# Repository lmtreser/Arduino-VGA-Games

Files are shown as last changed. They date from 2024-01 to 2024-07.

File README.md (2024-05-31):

# Arduino VGA Games

Implementación de videojuegos mediante la biblioteca [VGAX de Sandro Maffiodo](https://github.com/smaffer/vgax), un trabajo de [@Rob+Cai](https://www.instructables.com/member/Rob+Cai/). En el foro de Arduino hay un hilo ["Arduino color game (Bomber) using VGA library"](https://forum.arduino.cc/t/arduino-color-game-bomber-using-vga-library/316899) con más información y distintas versiones de juegos.

Uno de los juegos incluidos es [Pong! de Atari](https://es.wikipedia.org/wiki/Pong), el primer videojuego digital. A diferencia de otros, Pong utilizó un circuito totalmente digital para producir los gráficos, el sonido y el control del juego. No hay software ni CPU, sólo una colección de 66 circuitos integrados discretos que realizan una única función, interconectados para crear el juego que conocemos. En **/docs/PongSchematics.pdf** está el diagrama esquemático de la versión arcade original.

## Algunas fotos del primer prototipo

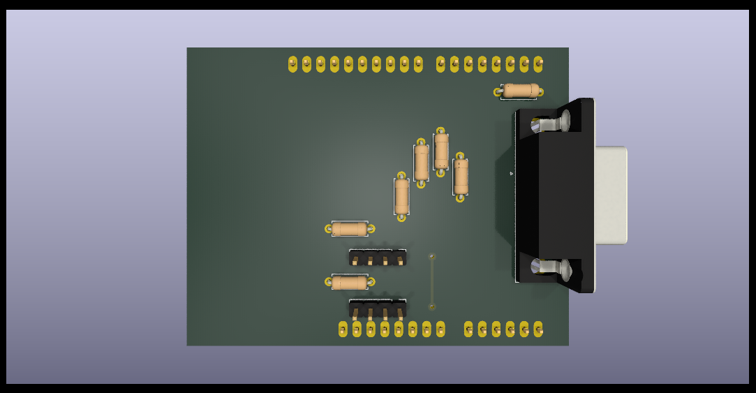
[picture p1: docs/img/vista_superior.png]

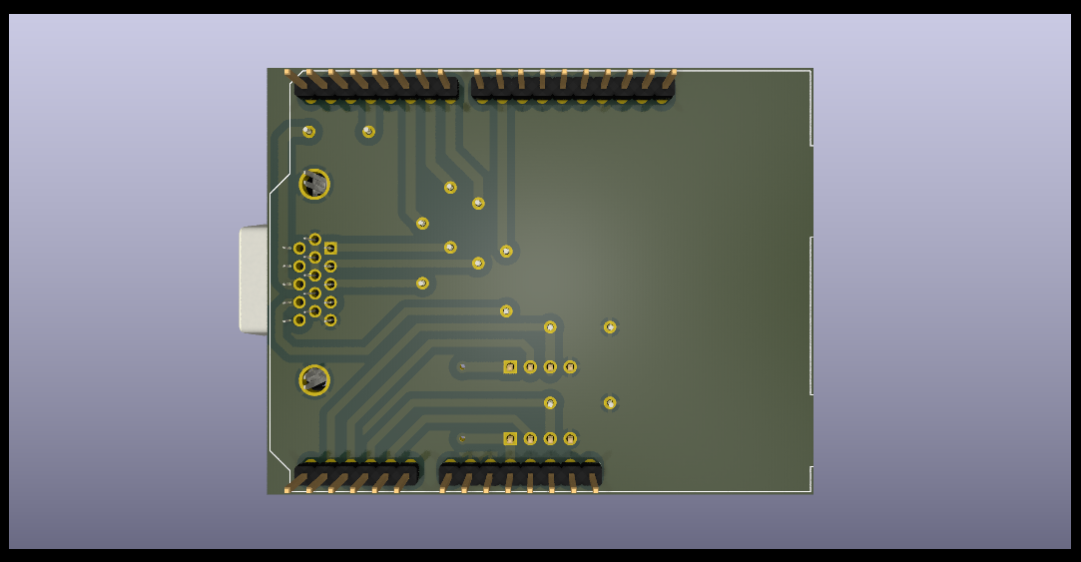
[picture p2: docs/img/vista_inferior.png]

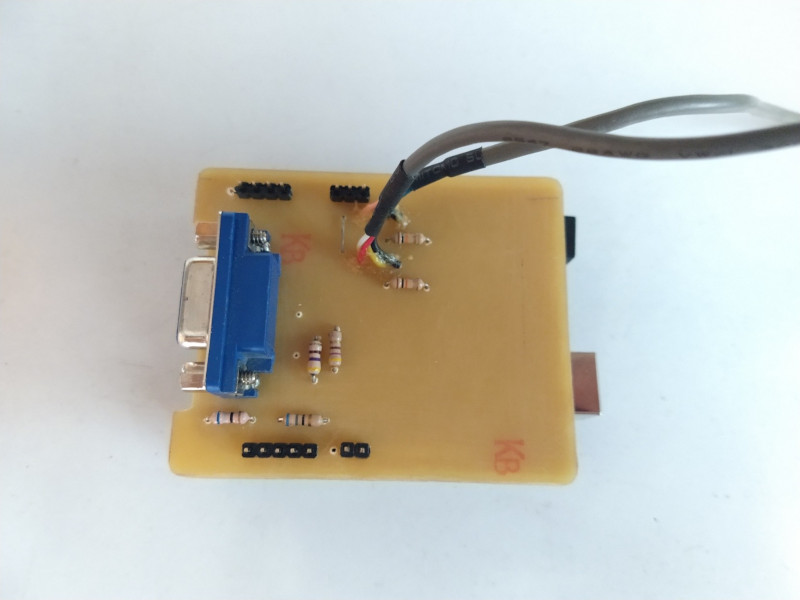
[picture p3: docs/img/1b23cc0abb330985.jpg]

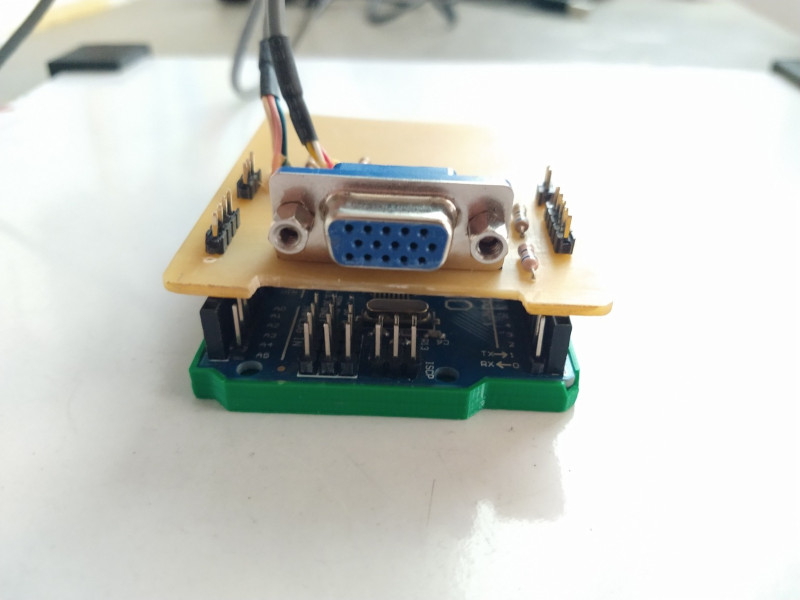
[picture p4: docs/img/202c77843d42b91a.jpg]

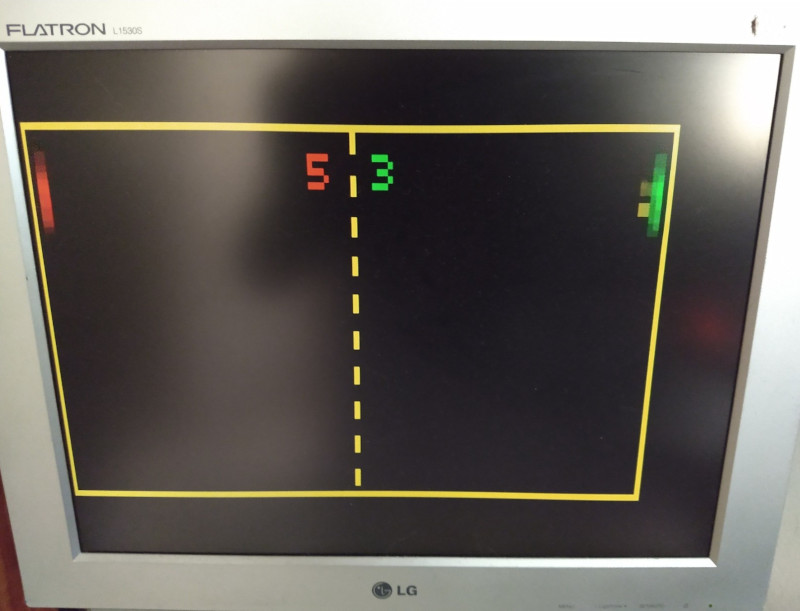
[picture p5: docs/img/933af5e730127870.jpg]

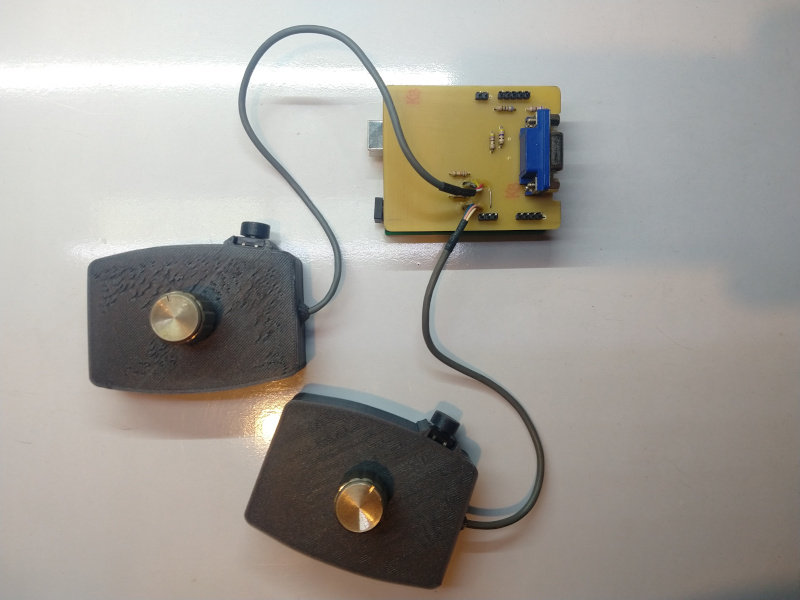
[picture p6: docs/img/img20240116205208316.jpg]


## Recursos

- Instructable ["VGA Games 4-in-1"](https://www.instructables.com/Arduino-VGA-Games-4-in-1/)
- Instructable ["Pong With Arduino Uno"](https://www.instructables.com/VGA-Pong-with-Arduino-Uno/)
- Biblioteca ["VGAX Library for Arduino UNO and MEGA"](https://github.com/smaffer/vgax)
- Otra biblioteca para explorar: ["APL"](https://github.com/akund/APL)
- Gabinete 3D ["USB paddle game controller"](https://www.thingiverse.com/thing:4223937)
- [The original Pong video game had no code](https://www.reddit.com/r/EngineeringPorn/comments/ul49zt/the_original_pong_video_game_had_no_code_and_was/)
- [Fabricating Hardware From The Original Arcade Pong Schematics](https://hackaday.com/2012/12/22/fabricating-hardware-from-the-original-arcade-pong-schematics/)

## Licencia

Tanto la **biblioteca VGAX** como el **firmware original de Rob+Cai** están protegidas por sus respectivas licencias, por favor consulte los sitios donde se alojan para mayor información. El resto del trabajo está protegido por la **Licencia MIT**. Puedes acceder a la versión original de la licencia (en inglés) a través del archivo [LICENSE](./LICENSE) o en línea en [The MIT License (MIT)](https://mit-license.org/). También proporcionamos una traducción no oficial desde [Wikipedia](https://es.m.wikipedia.org/wiki/Licencia_MIT#La_licencia):

Copyright (c) 2024 Lucas Martín Treser

Por la presente se concede permiso, libre de cargos, a cualquier persona que obtenga una copia de este software y de los archivos de documentación asociados (el "Software"), a utilizar el Software sin restricción, incluyendo sin limitación los derechos a usar, copiar, modificar, fusionar, publicar, distribuir, sublicenciar, y/o vender copias del Software, y a permitir a las personas a las que se les proporcione el Software a hacer lo mismo, sujeto a las siguientes condiciones:

El aviso de copyright anterior y este aviso de permiso se incluirán en todas las copias o partes sustanciales del Software.

EL SOFTWARE SE PROPORCIONA "COMO ESTÁ", SIN GARANTÍA DE NINGÚN TIPO, EXPRESA O IMPLÍCITA, INCLUYENDO PERO NO LIMITADO A GARANTÍAS DE COMERCIALIZACIÓN, IDONEIDAD PARA UN PROPÓSITO PARTICULAR E INCUMPLIMIENTO. EN NINGÚN CASO LOS AUTORES O PROPIETARIOS DE LOS DERECHOS DE AUTOR SERÁN RESPONSABLES DE NINGUNA RECLAMACIÓN, DAÑOS U OTRAS RESPONSABILIDADES, YA SEA EN UNA ACCIÓN DE CONTRATO, AGRAVIO O CUALQUIER OTRO MOTIVO, DERIVADAS DE, FUERA DE O EN CONEXIÓN CON EL SOFTWARE O SU USO U OTRO TIPO DE ACCIONES EN EL SOFTWARE.

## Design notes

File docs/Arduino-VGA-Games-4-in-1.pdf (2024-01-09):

http://www.instructables.com/id/Arduino-VGA-Games-4-in-1/technology (http://www.instructables.com/tag/type-id/category-technology/) workshop (http://www.instructables.com/tag/type-id/category-workshop/) craft (http://www.instructables.com/tag/type-id/category-craft/) home (http://www.instructables.com/tag/type-id/category-home/) food (http://www.instructables.com/tag/type-id/category-food/) play (http://www.instructables.com/tag/type-id/category-play/) outside (http://www.instructables.com/tag/type-id/category-outside/) costumes (http://www.instructables.com/tag/type-id/category-costumes/)

# Arduino VGA games 4-in-1

by Rob Cai on December 29, 2016

Table of Contents

## Intro: Arduino VGA games 4-in-1

After the publication of the Arduino VGAx library (https://github.com/smaffer/vgax) on GitHub done by Sandro Maffiodo aka Smaffer, I have reproduced and published on Instructable some of the most famous classical games. Recently I decided to put four of them together, in particular: Pong, Breakout, Bomber and a drawing toy inspired to Etch-a-Sketch.

The hardware is simply the same of my first Instructables: VGA Pong with Arduino Uno. (http://www.instructables.com/id/VGA-Pong-with-Arduino-Uno/)

The only needed components are two potentiometers, two buttons, few resistors and a DSUB15 (VGA) connector. As usual, no supporting IC or special shields!

You can see the 4-in-1 games in action in this (https://www.youtube.com/watch?v=HupxNI5VUGE) video.

The VGAx library allows to use four color with a resolution of 120 x 60 pixels, not many but enough for this retro-game “console”. The graphic is raw but, thanks to the use of the potentiometers, the games run smoothly. Simple sound effects are available too.

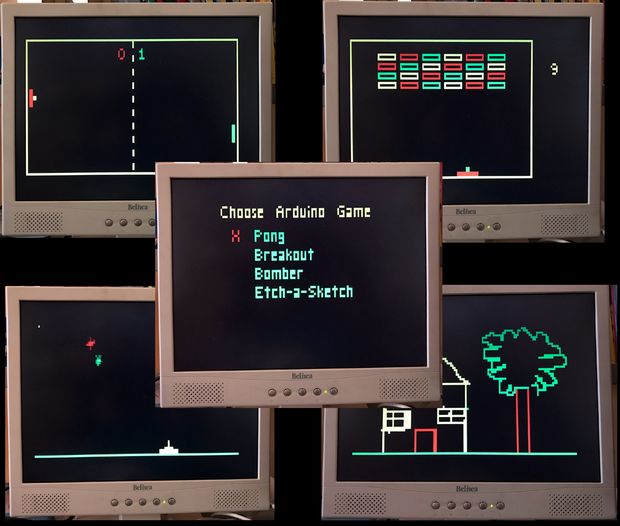
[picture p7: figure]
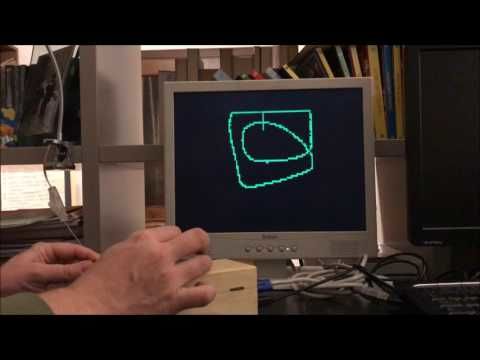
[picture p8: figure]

## Step 1: How to build your own "4-in-1 games" with Arduino

First download " ArduinoVGAgames" code at the bottom of this page and copy it on your PC in a directory with the same name. Then download the Smaffer’s VGAx libraries from this link (https://github.com/smaffer/vgax) on GitHub. The easiest way is to copy them in the Arduino software subfolder named "libraries", to be immediately recognized.

Uploaded then the code in your Arduino (I tested Uno and Nano). A worning for low available memory is normal. If you do not have other errors everything is ok and you can immediately start to build your own console.

For this you need:
an Arduino Uno Rev. 3 or an Arduino Nano 3.x
a DSUB15 Connector, i.e. a VGA female connector or a VGA cable to be cut four resistors: 2 x 68 Ohm and 2 x 470 Ohm
two 10 kOhm linear potentiometers (similar values are fine too)
two buttons other two resistors (from 1 to 2 kOhm are fine)
some piece of cable + breadboard or a strip board
facultative: a piezo speaker

The schematic is reported at the beginning of this Instructable, together with an overview of the finished “console”. The speaker must be connected to analog pin A0.

I placed the Arduino board with the VGA connector in a wood box, which holds also the second player potentiometer and button, while the main player potentiometer and button are in a separate and smaller box.

If you decide to reproduce this toy, I appreciate if you write a comment or send a picture in the comment section below.

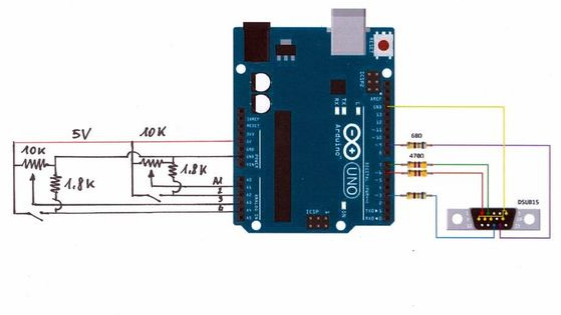
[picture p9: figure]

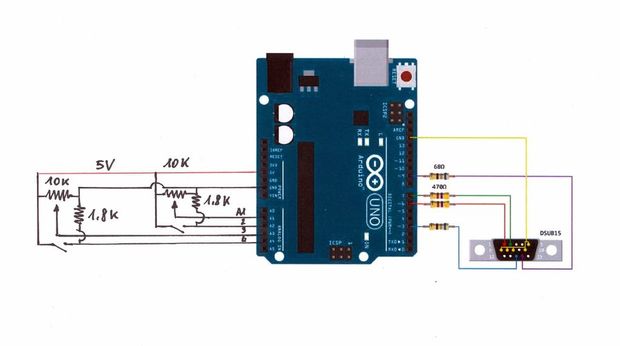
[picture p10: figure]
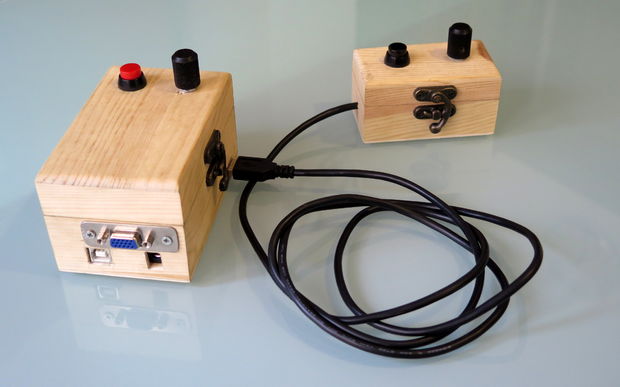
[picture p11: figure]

File Downloads

ArduinoVGAgame.ino (http://www.instructables.comhttps://cdn.instructables.com/ORIG/FQX/OHOC/IX6FVPA1/FQXOHOCIX6FVPA1.ino) (37 KB)

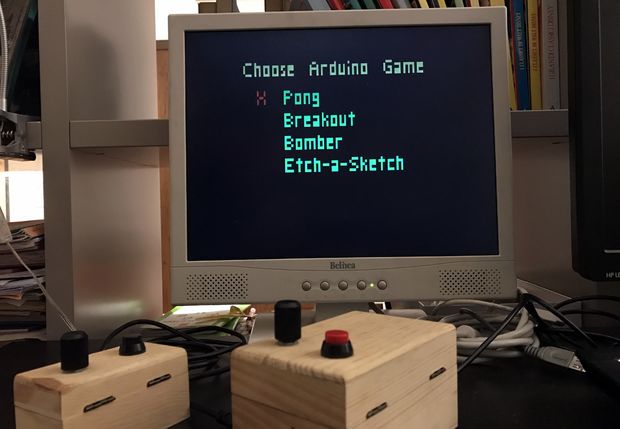
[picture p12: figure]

[NOTE: When saving, if you see .tmp as the file ext, rename it to 'ArduinoVGAgame.ino'] (http://www.instructables.comhttps://cdn.instructables.com/ORIG/FQX/OHOC/IX6FVPA1/FQXOHOCIX6FVPA1.ino)

## Step 2: Some final comment

Joining four games in one was challenging, due to the Arduino lack of SRAM, the real bottle-neck of the VGA performances.

The AVR microcontroller has only 2048 bytes available to store and manipulate the variables. On the other hand the VGAx library stores the screen variables in a 120x60 pixels framebuffer where each pixel needs 2 bits (4 colors), for a total of 1800 bytes.

Only 248 bytes are then available for the sketch variables but, in my experience, one should leave at least 100 bytes free to avoid instabilities.

The VGA standard has been officially put in retirement in 2015, for being substituted with HDMI, and nowadays is almost impossible to find a new monitor or TV that implements it.

The question is then: does it make sense to produce an Arduino game for this standard? Well, I believe the answer is yes! For this reason, nowadays, almost everybody has an old and unused VGA monitor, eventually 4:3, still working fine, since it has been replaced with an HD one. If you, as I do, feel sorry to throw in the waste a working yet obsolete device, you can convert it in an old style retro-gaming station by means of a bare Arduino and few other components.

## Related Instructables

VGA Etch-a-Sketch with
Arduino Uno (http://www.instructables.com/id/VGA-Etch-a-Sketch-With-Arduino-Uno/) by
Rob Cai

VGA Pong with
Arduino Uno (http://www.instructables.com/id/VGA-Pong-with-Arduino-Uno/?utm_source=pdf&utm_campaign=related) by
Rob Cai

VGA Bomber
With Arduino
Uno (http://www.instructables.com/id/VGA-Bomber-With-Arduino-Uno/?utm_source=pdf&utm_campaign=related) by Rob Cai

VGA Snake with
Arduino Uno (http://www.instructables.com/id/VGA-Snake-with-Arduino-Uno/?utm_source=pdf&utm_campaign=related) by
Rob Cai

VGA Breakout
with Arduino
Uno (http://www.instructables.com/id/VGA-Breakout-With-Arduino-Uno/?utm_source=pdf&utm_campaign=related) by Rob Cai

VGA Tetris with
Arduino Uno (http://www.instructables.com/id/VGA-Tetris-With-Arduino-Uno/?utm_source=pdf&utm_campaign=related) by
Rob Cai

Advertisements

## Comments

1 comments | Add Comment (http://www.instructables.com/id/Arduino-VGA-Games-4-in-1/)
PiotrS (http://www.instructables.com/member/PiotrS/?utm_source=pdf&utm_campaign=comments) says: | Dec 29, 2016. 12:45 PM REPLY (http://www.instructables.com/id/Arduino-VGA-Games-4-in-1/)
This is amazing i can show my daughter how it was done in my ages :)

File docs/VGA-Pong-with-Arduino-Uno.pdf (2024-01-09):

http://www.instructables.com/id/VGA-Pong-with-Arduino-Uno/technology (http://www.instructables.com/tag/type-id/category-technology/) workshop (http://www.instructables.com/tag/type-id/category-workshop/) craft (http://www.instructables.com/tag/type-id/category-craft/) home (http://www.instructables.com/tag/type-id/category-home/) food (http://www.instructables.com/tag/type-id/category-food/) play (http://www.instructables.com/tag/type-id/category-play/) outside (http://www.instructables.com/tag/type-id/category-outside/) costumes (http://www.instructables.com/tag/type-id/category-costumes/)

# VGA Pong with Arduino Uno

by Rob Cai on September 17, 2015

Table of Contents

## Intro: VGA Pong with Arduino Uno

I have repruduced a color version of the classic Pong running for a VGA monitor, using a bare Arduino Uno.

It is for two players and it has sound too. It has four colors and a resolution of 120 x 60 pixels.

My goal was to avoid any special shield or support IC!

I just used few resistors, a DSUB15 connector, a pair of potenziometers and buttons. The Arduino board and the others components are placed in two wood boxes. The second player paddle is connected to the main block by means of a recycled USB cable. Pictures of the whole "console" and a simple schematic are shown at the beginning of this video:

In the past I have reproduced the B&W version for TV, using the TVout libraries...

...but now, insted of the TVout library, the color Pong is done using the VGAx library recently written by Smaffer.

You can read further the details in this Arduino forum (http://forum.arduino.cc/index.php?topic=328631.new#new)
Instructions to built your own Color Pong with Arduino

In brief, here (http://forum.arduino.cc/index.php?action=dlattach;topic=328631.0;attach=135889) you can download the latest code version, then you need the VGAx libraries from Smaffer on github published here. (https://github.com/smaffer/vgax)

Once you have the code uploaded an an Arduino Uno (I have Rev. 3) without errors, you can start to build your own console.

You need:
1. an Arduino Uno Rev. 3
2. DSUB15 Connector, i.e. a VGA female connector or a VGA cable to be cut.
3. four resistors: 2 x 68 Ohm and 2 x 470 Ohm
4. two 10 kOhm potentiometers
5. two buttons
6. other two resistors (from 1 to 2 kOhm are fine)
7. some piece of cable
8. facoltative: an USB female plug and an USB cable for the second player, or any other connector/cable with four wires

The schematic is reported at the beginning of this Instructable, together with an overview of the finished consolle and how the game looks on my TV.

I placed the Arduino board with the VGA connector in a wood box, which holds also the first player potentiometer and button. I used a second smaller wood box for the second player and I decided to connect it to the main one by means of an USB female plug and an USB cable. You can use any other connector/cable wich contains at least four separated wires.

Enjoy!

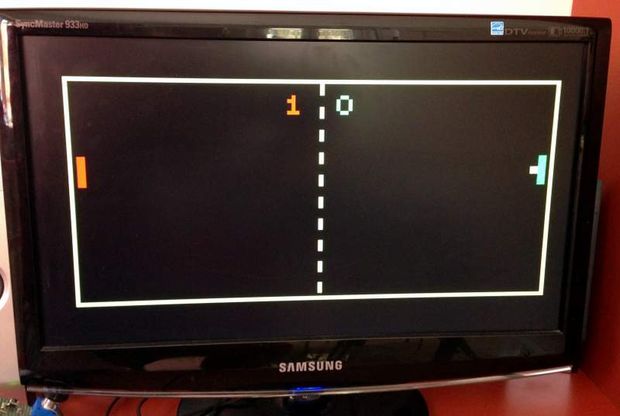
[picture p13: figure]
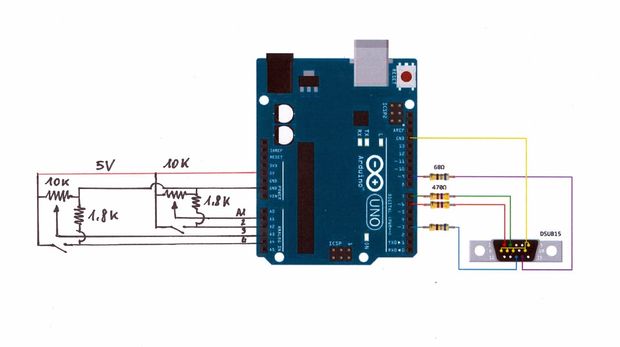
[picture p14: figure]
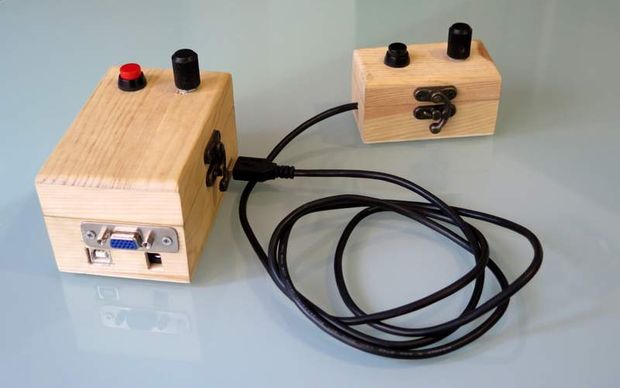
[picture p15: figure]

## Related Instructables

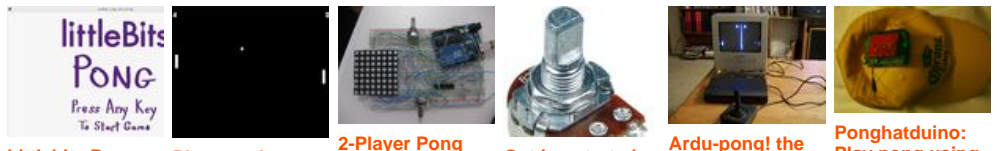
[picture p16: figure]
Ponghatduino:

Littlebits Pong (http://www.instructables.com/id/Littlebits-Pong/?utm_source=pdf&utm_campaign=related)
by Louisville
Public Library

Photo resistor
controlled
arduino pong
with processing (http://www.instructables.com/id/Photo-resistor-controlled-arduino-pong-with-proces/)
by GIV-ENG-2014 (http://www.instructables.com/member/GIV-ENG-2014/?utm_source=pdf&utm_campaign=related)

2-Player Pong
Game Using
Arduino Uno
and 8x8 Led
Matrix (http://www.instructables.com/id/2-Player-Pong-Game-Using-Arduino-Uno-and-8x8-Led-M/) (video) (http://www.instructables.com/id/2-Player-Pong-Game-Using-Arduino-Uno-and-8x8-Led-M/) by
onuravun (http://www.instructables.com/member/onuravun/?utm_source=pdf&utm_campaign=related)

Getting started
with Arduino -
Potentiometer
Pong (http://www.instructables.com/id/Getting-started-with-Arduino-Potentiometer-Pong/) by Digital
Art and
Technology

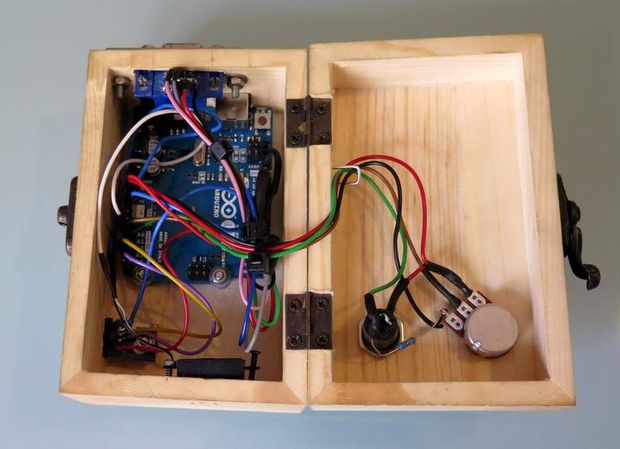
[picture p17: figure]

Ardu-pong! the
Arduino based
pong console (http://www.instructables.com/id/Ardu-pong-the-Arduino-based-pong-console/) by
kyle brinkerhoff

Play pong using
your hat (http://www.instructables.com/id/Ponghatduino-Play-pong-using-your-hat/) by
RonanOD (http://www.instructables.com/member/RonanOD/?utm_source=pdf&utm_campaign=related)

Advertisements

## Comments

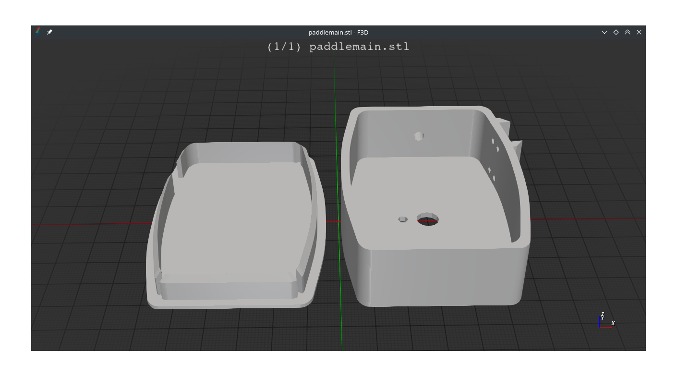
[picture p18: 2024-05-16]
docs/poster/case.png

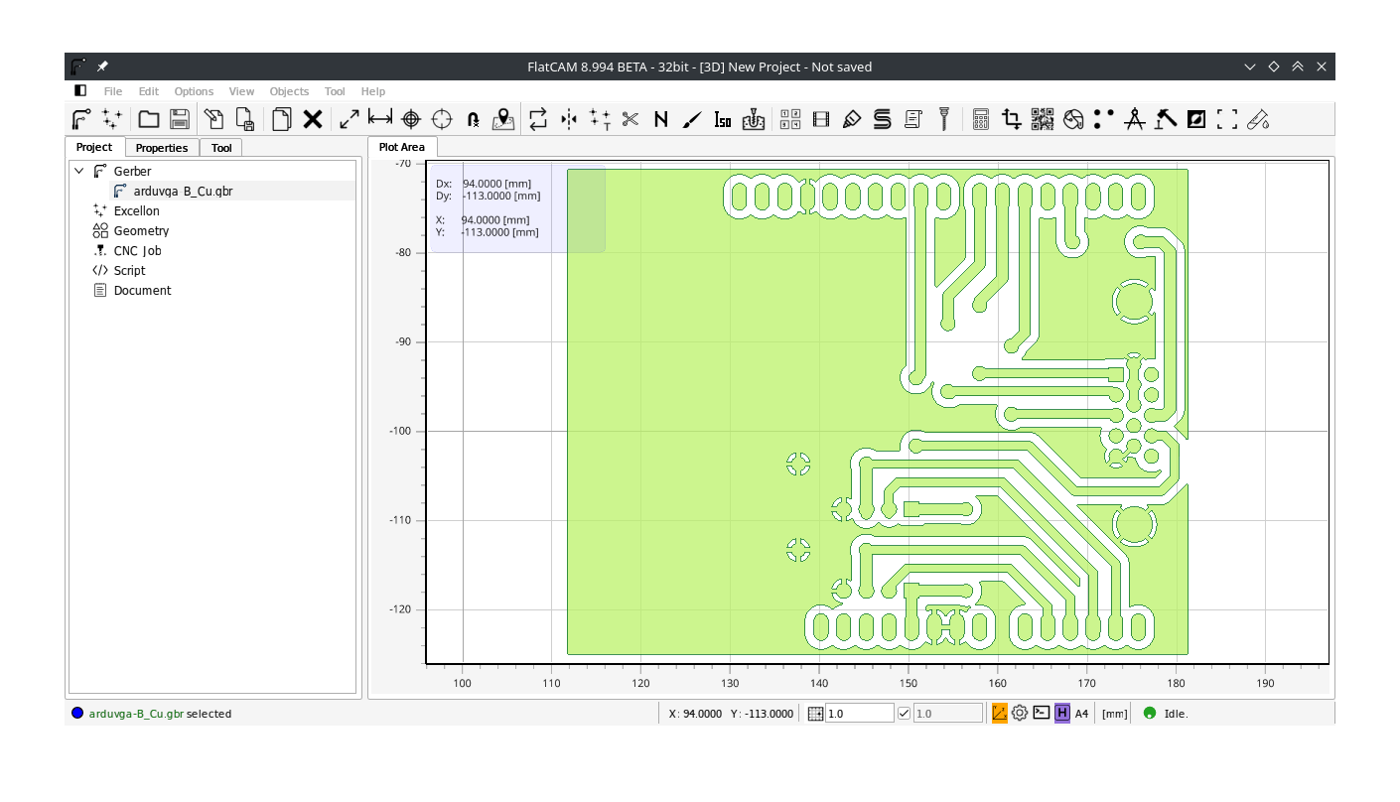
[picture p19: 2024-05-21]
docs/poster/flatcam.png

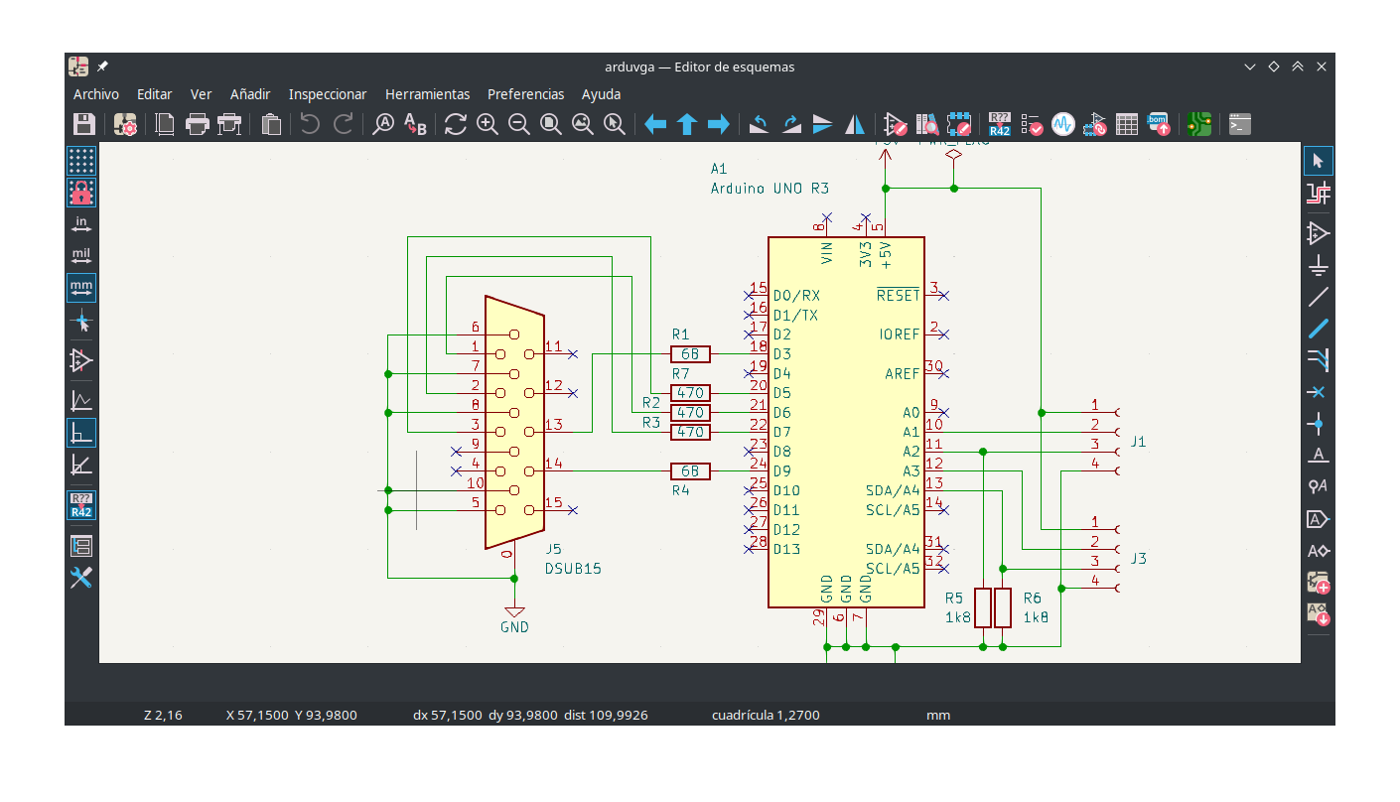
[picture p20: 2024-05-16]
docs/poster/kicad_sch.png

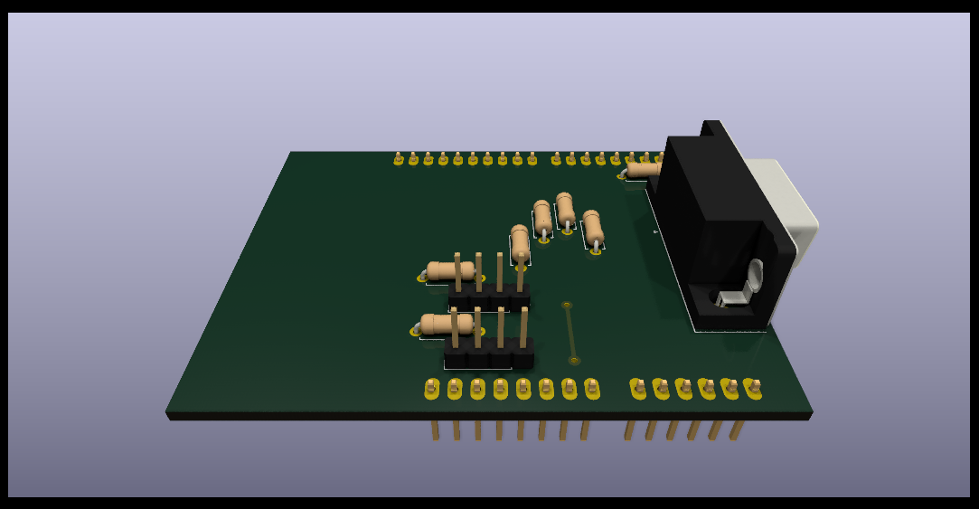
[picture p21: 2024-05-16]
docs/poster/kicad_3d.png

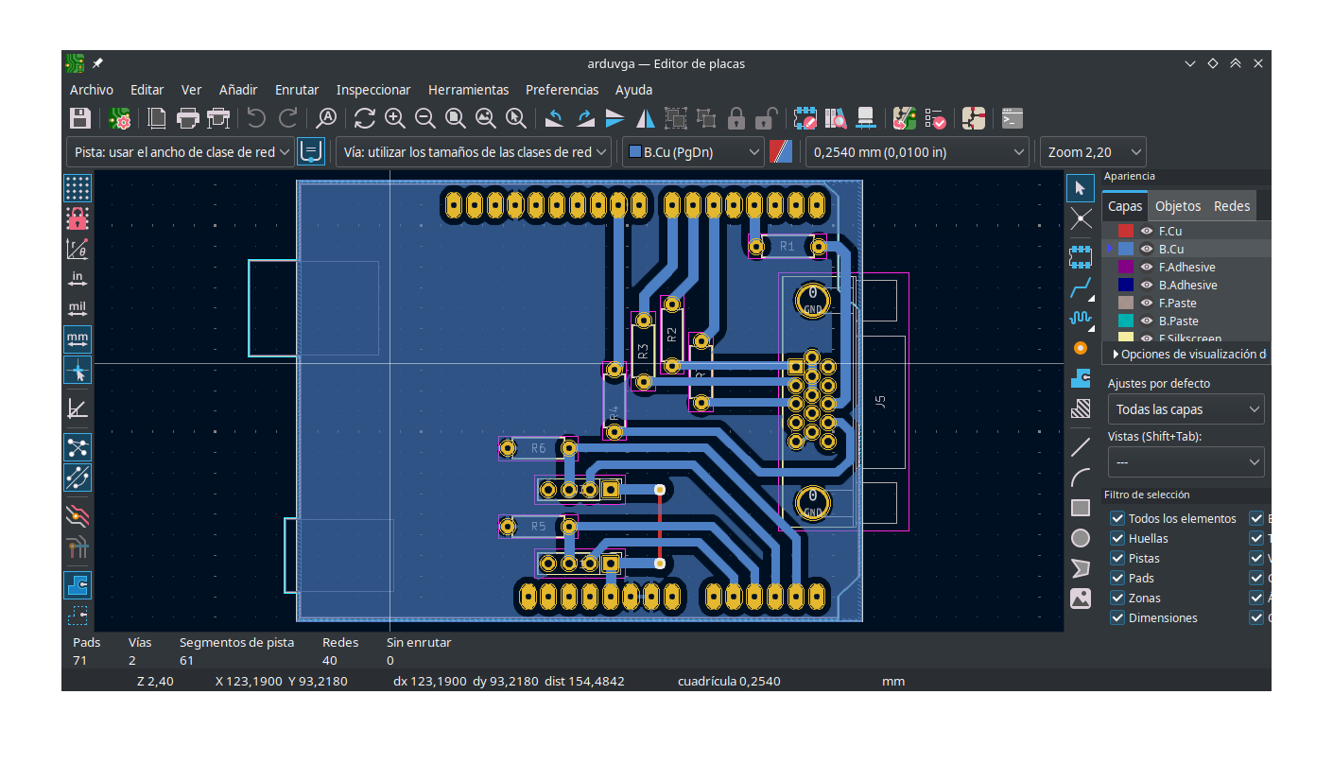
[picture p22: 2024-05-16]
docs/poster/kicad_brd.png

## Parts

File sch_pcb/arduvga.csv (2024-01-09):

Source: | /home/lucas/Downloads/1sch_brd/arduvga.kicad_sch
Date: | mar 09 ene 2024 11:10:10
Tool: | Eeschema 7.0.10-7.0.10~ubuntu23.10.1
Generator: | /usr/share/kicad/plugins/bom_csv_grouped_by_value.py
Component Count: | 17
Collated Components:
Item | Qty | Reference(s) | Value | LibPart | Footprint | Datasheet | DNP
1 | 1 | A1 | Arduino UNO R3 | MCU_Module:Arduino_UNO_R3 | Module:Arduino_UNO_R3 | https://www.arduino.cc/en/Main/arduinoBoardUno
2 | 2 | J1, J3 | Conn_01x04_Socket | Connector:Conn_01x04_Socket | Connector_PinHeader_2.54mm:PinHeader_1x04_P2.54mm_Vertical | ~
3 | 2 | J2, J4 | Conn_01x04_Pin | Connector:Conn_01x04_Pin |  | ~
4 | 1 | J5 | DSUB15 | Connector:DB15_Female_HighDensity_MountingHoles | Connector_Dsub:DSUB-15-HD_Female_Horizontal_P2.29x1.98mm_EdgePinOffset3.03mm_Housed_MountingHolesOffset4.94mm | ~
5 | 2 | R1, R4 | 68 | Device:R | Resistor_THT:R_Axial_DIN0207_L6.3mm_D2.5mm_P7.62mm_Horizontal | ~
6 | 3 | R2, R3, R7 | 470 | Device:R | Resistor_THT:R_Axial_DIN0207_L6.3mm_D2.5mm_P7.62mm_Horizontal | ~
7 | 2 | R5, R6 | 1k8 | Device:R | Resistor_THT:R_Axial_DIN0207_L6.3mm_D2.5mm_P7.62mm_Horizontal | ~
8 | 2 | RV1, RV2 | 10k | Device:R_Potentiometer |  | ~
9 | 2 | SW1, SW2 | Push | Switch:SW_Push |  | ~

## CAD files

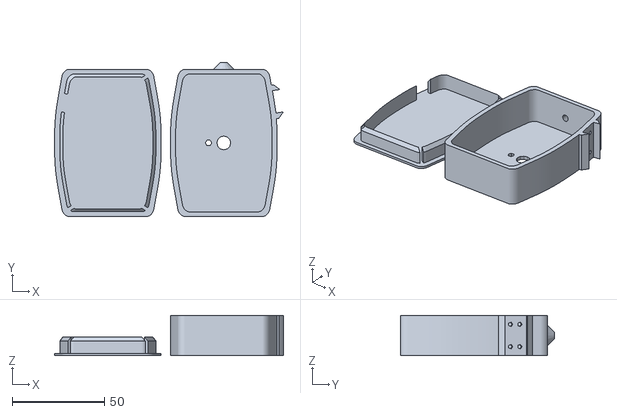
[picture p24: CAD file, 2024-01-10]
case/files/paddlemain.stl
124.4 x 83.7 x 22.0

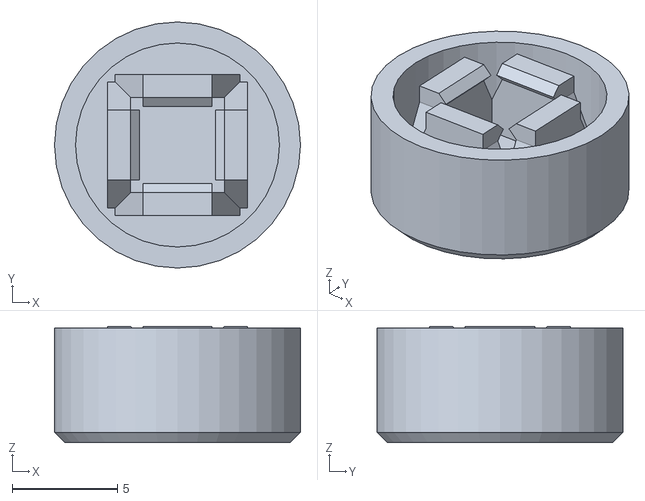
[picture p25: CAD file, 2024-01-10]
case/files/buttoncap110.stl
11.7 x 11.7 x 5.53

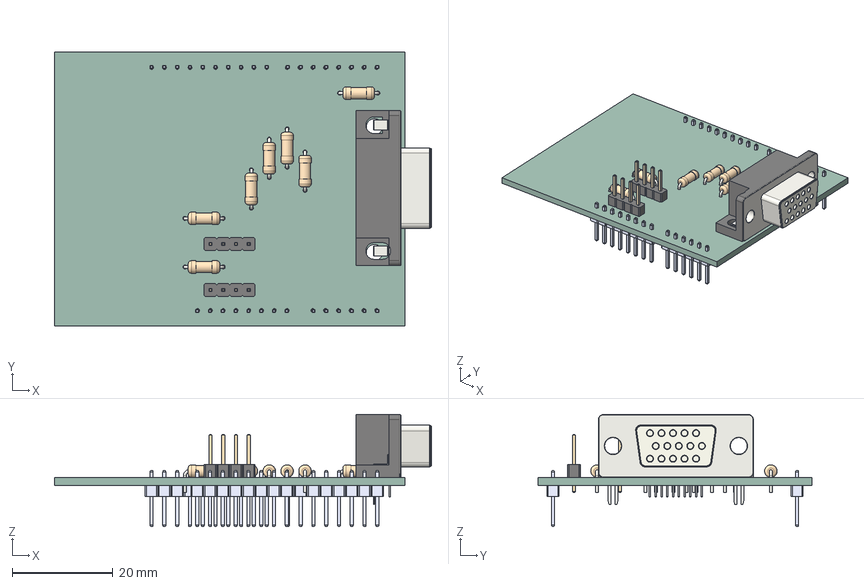
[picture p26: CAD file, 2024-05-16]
sch_pcb/arduvga.step
74.9 x 54.4 x 22.3 mm
DSUB_30_female
R_Axial_DIN0207_L63mm_D25mm_P762mm_Horizontal x 7
PinHeader_1x04_P254mm_Vertical x 2
6x_Male_Pin_2.54_mm
8x_Male_Pin_2.54_mm x 2
10x_Male_Pin_2.54_mm
arduvga_PCB

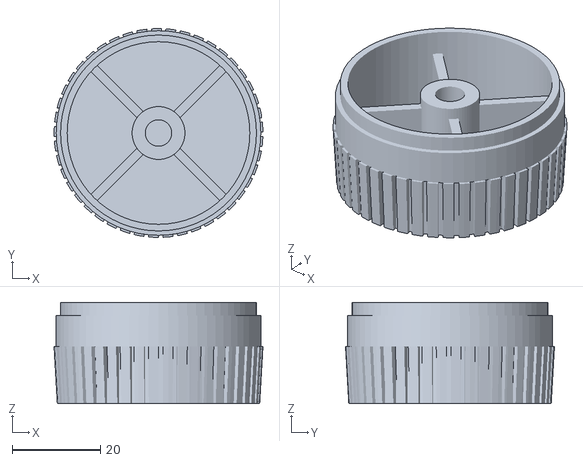
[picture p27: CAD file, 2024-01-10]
case/files/paddleknob.stl
47.5 x 47.5 x 23.0

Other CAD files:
case/files/buttoncap-standalone.scad
case/files/paddleknob.scad
case/files/paddlemain-standalone.scad

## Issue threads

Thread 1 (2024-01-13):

Tamaño de pads

lmtreser, 2024-01-13:
Verificar el tamaño de los _pads_ de los _pinheaders_, tanto en los conectores que van hacia la placa Arduino, como el de los conectores de los joysticks. Probablemente habrá que modificar la biblioteca de los componentes utilizados.

lmtreser, 2024-01-13:
Se modificó el footprint del shield Arduino Uno.

Closed 2024-01-13.

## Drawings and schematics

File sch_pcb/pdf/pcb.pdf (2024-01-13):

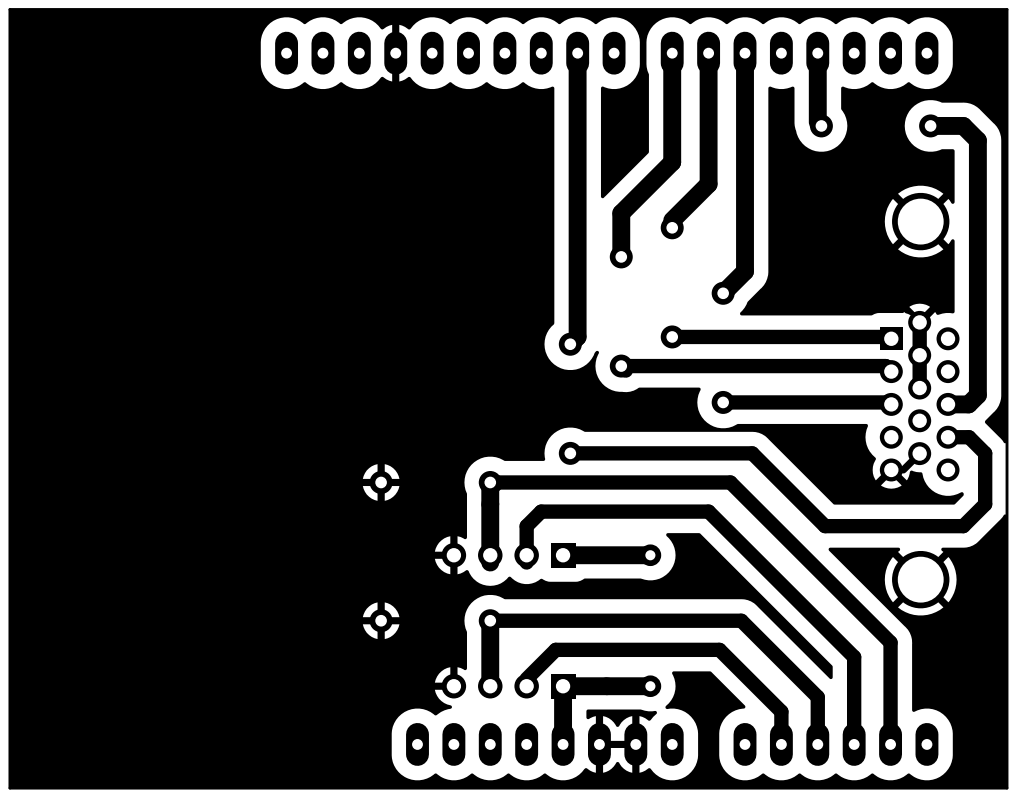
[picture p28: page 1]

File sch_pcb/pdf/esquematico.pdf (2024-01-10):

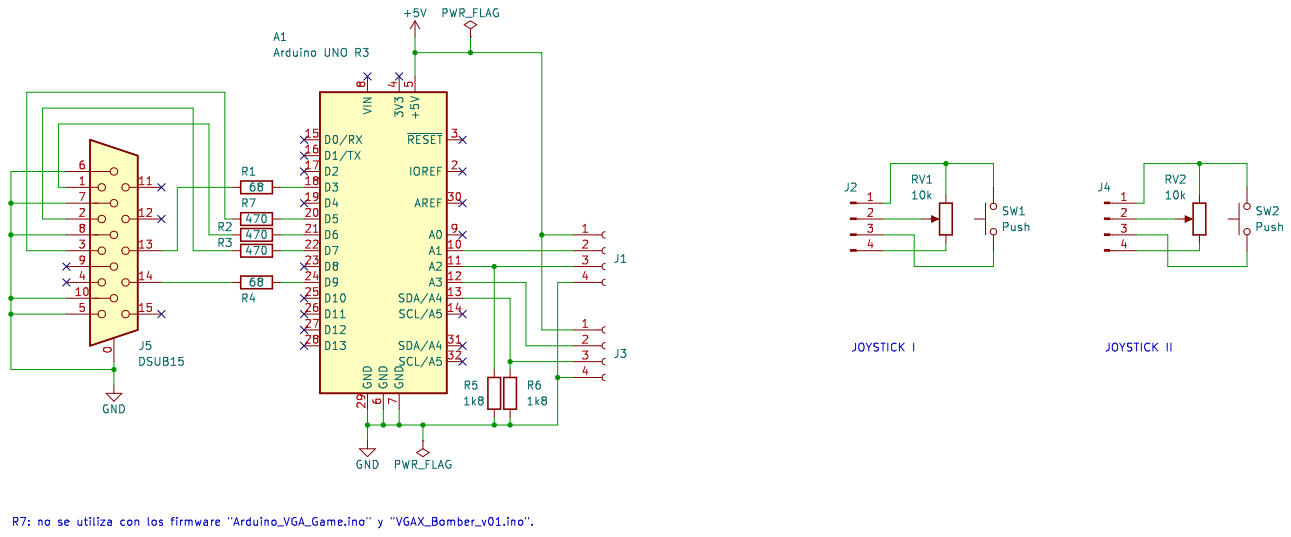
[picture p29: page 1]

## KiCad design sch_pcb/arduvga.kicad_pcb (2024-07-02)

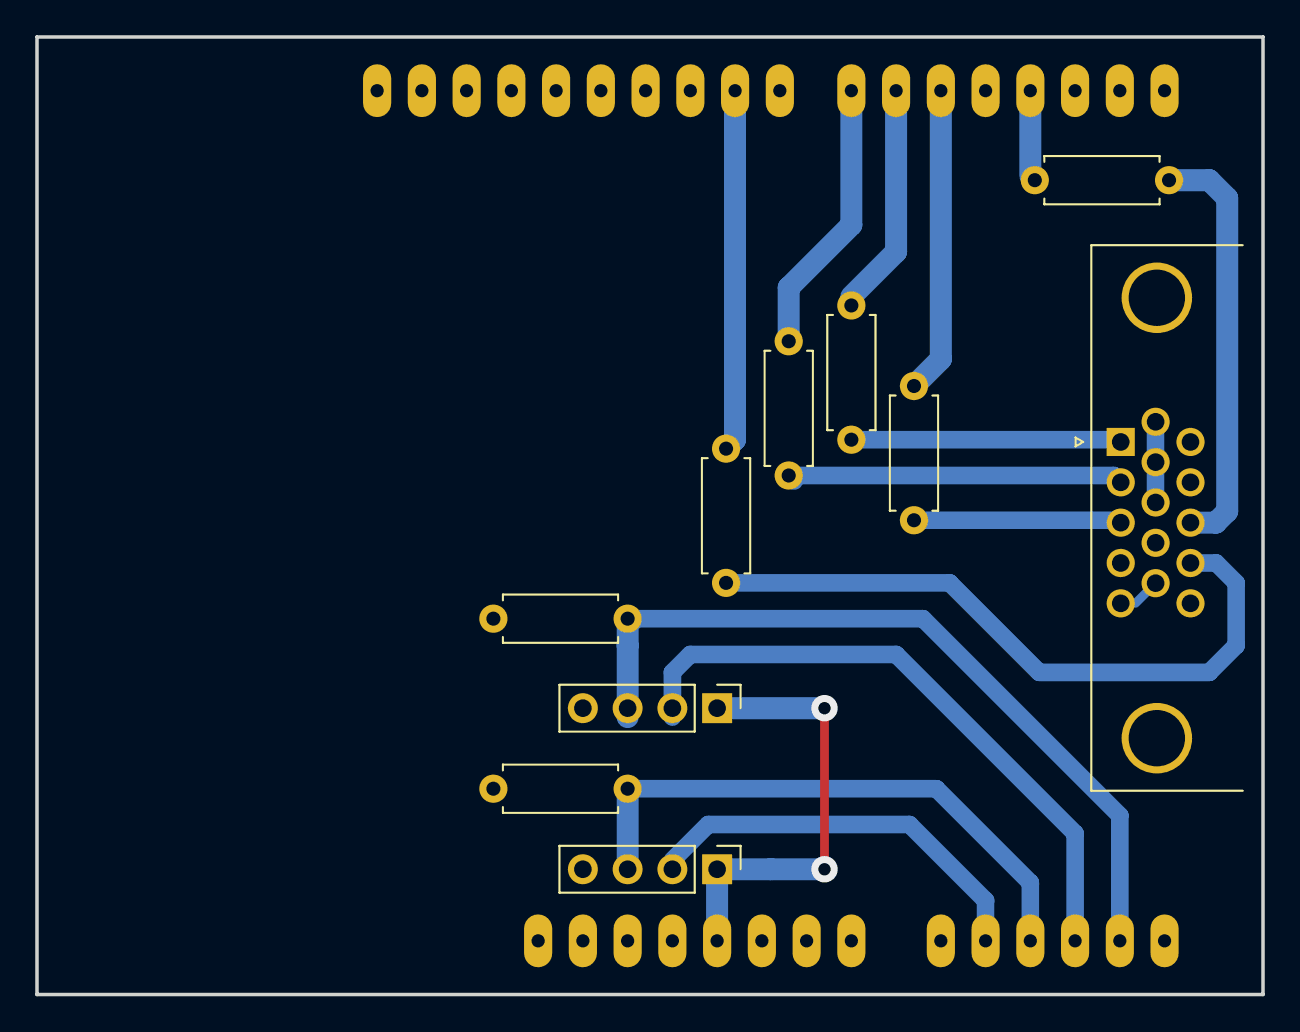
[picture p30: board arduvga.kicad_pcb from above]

Board: 2 copper layers, 69.6 x 54.4 mm, 11 parts (1 on the bottom side), 16 nets.

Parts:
A1: Arduino UNO R3; Arduino_UNO_R3_OVAL
J1, J3: Conn_01x04_Socket; PinHeader_1x04_P2.54mm_Vertical
J5: DSUB15; DSUB-15-HD_Female_Horizontal_P2.29x1.98mm_EdgePinOffset3.03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
R1, R4: 68; R_Axial_DIN0207_L6.3mm_D2.5mm_P7.62mm_Horizontal
R2, R3, R7: 470; R_Axial_DIN0207_L6.3mm_D2.5mm_P7.62mm_Horizontal
R5, R6: 1k8; R_Axial_DIN0207_L6.3mm_D2.5mm_P7.62mm_Horizontal

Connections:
+5V: A1.5 (+5V), J1.1, J3.1
GND: A1.6 (GND), A1.7 (GND), A1.29 (GND), J1.4, J3.4, J5.0, J5.5, J5.6, J5.7, J5.8, J5.10, R5.2, R6.2
unnamed: A1.10 (A1), J1.2
unnamed: A1.11 (A2), J1.3, R5.1
unnamed: A1.12 (A3), J3.2
unnamed: A1.18 (D3), R1.2
unnamed: A1.20 (D5), R7.2
unnamed: A1.21 (D6), R2.2
unnamed: A1.22 (D7), R3.2
unnamed: A1.24 (D9), R4.2
unnamed: A1.13 (SDA/A4), J3.3, R6.1
unnamed: J5.1, R2.1
unnamed: J5.2, R3.1
unnamed: J5.3, R7.1
unnamed: J5.13, R1.1
unnamed: J5.14, R4.1

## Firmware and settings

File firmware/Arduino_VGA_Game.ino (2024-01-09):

/******************************************************************* 
*                                                                  * 
*  Arduino VGA Game is a game consolle for VGA monitors,           * 
*  written by Roberto Melzi - December the 24th, 2016              * 
*  Arduino software version: 1.6.4                                 * 
*  ArduinoVGAgame Version 01                                       * 
*                                                                  * 
*  VGAx Library written By Sandro Maffiodo aka Smaffer.            * 
*  Version downloaded on August the 17th 2015) here:               * 
*  https://github.com/smaffer/vgax                                 * 
*  See also the Arduino forum:                                     * 
*  http://forum.arduino.cc/index.php?topic=328631.0                * 
*  and on Instructables:                                           *
*  http://www.instructables.com/member/Rob%20Cai/instructables/    *
*                                                                  * 
*******************************************************************/ 

#include <VGAX.h>
#include <math.h>
#include <VGAXUtils.h> 

#define FNT_NANOFONT_HEIGHT 6
#define FNT_NANOFONT_SYMBOLS_COUNT 95
#define PADDLE_HEIGHT 8
#define PADDLE_WIDTH 2
#define RIGHT_PADDLE_X (VGAX_WIDTH-4)
#define LEFT_PADDLE_X 2
#define MAX_Y_VELOCITY 0.1
#define WHEEL_ONE_PIN 3   //analog
#define WHEEL_TWO_PIN 1   //analog
#define BUTTON_ONE_PIN A4 //digital 
#define BUTTON_TWO_PIN A2 //digital 
// NB: pin A0 is used for the sound 

VGAX vga;
VGAXUtils vgaU;

//data size=570 bytes
const unsigned char fnt_nanofont_data[FNT_NANOFONT_SYMBOLS_COUNT][1+FNT_NANOFONT_HEIGHT] PROGMEM={
{ 1, 128, 128, 128, 0, 128, 0, }, //glyph '!' code=0
{ 3, 160, 160, 0, 0, 0, 0, }, //glyph '"' code=1
//{ 5, 80, 248, 80, 248, 80, 0, },  //glyph '#' code=2
//{ 5, 248, 248, 248, 248, 248, 0, },  //glyph '#' code=2 - full rectangle
{ 5, 240, 240, 240, 240, 240, 240, },  //glyph '#' = 'full rectangle' code=2
//{ 5, 32, 160, 240, 120, 32, 32, },  //glyph '#' = 'planeR' code=2
{ 3, 80, 32, 112, 112, 32, 0, },  //glyph '$' = 'bomb' code=3
{ 5, 32, 40, 120, 240, 32, 32, },  //glyph '%' = 'planeL' code=4
{ 5, 96, 144, 104, 144, 104, 0, },  //glyph '&' code=5
{ 5, 248, 248, 248, 248, 248, 248, },  //glyph ''' = 'rectangle 5 x 6' code=6
//{ 5, 120, 160, 112, 40, 240, 0, },  //glyph '$' code=3
//{ 5, 136, 16, 32, 64, 136, 0, },  //glyph '%' code=4
//{ 5, 96, 144, 104, 144, 104, 0, },  //glyph '&' code=5
//{ 2, 128, 64, 0, 0, 0, 0, },  //glyph ''' code=6
{ 2, 64, 128, 128, 128, 64, 0, }, //glyph '(' code=7
{ 2, 128, 64, 64, 64, 128, 0, },  //glyph ')' code=8
{ 3, 0, 160, 64, 160, 0, 0, },  //glyph '*' code=9
{ 3, 0, 64, 224, 64, 0, 0, }, //glyph '+' code=10
{ 2, 0, 0, 0, 0, 128, 64, },  //glyph ',' code=11
{ 3, 0, 0, 224, 0, 0, 0, }, //glyph '-' code=12
{ 1, 0, 0, 0, 0, 128, 0, }, //glyph '.' code=13
{ 5, 8, 16, 32, 64, 128, 0, },  //glyph '/' code=14
{ 4, 96, 144, 144, 144, 96, 0, }, //glyph '0' code=15
{ 3, 64, 192, 64, 64, 224, 0, },  //glyph '1' code=16
{ 4, 224, 16, 96, 128, 240, 0, }, //glyph '2' code=17
{ 4, 224, 16, 96, 16, 224, 0, },  //glyph '3' code=18
{ 4, 144, 144, 240, 16, 16, 0, }, //glyph '4' code=19
{ 4, 240, 128, 224, 16, 224, 0, },  //glyph '5' code=20
{ 4, 96, 128, 224, 144, 96, 0, }, //glyph '6' code=21
{ 4, 240, 16, 32, 64, 64, 0, }, //glyph '7' code=22
{ 4, 96, 144, 96, 144, 96, 0, },  //glyph '8' code=23
{ 4, 96, 144, 112, 16, 96, 0, },  //glyph '9' code=24
{ 1, 0, 128, 0, 128, 0, 0, }, //glyph ':' code=25
{ 2, 0, 128, 0, 0, 128, 64, },  //glyph ';' code=26
{ 3, 32, 64, 128, 64, 32, 0, }, //glyph '<' code=27
{ 3, 0, 224, 0, 224, 0, 0, }, //glyph '=' code=28
{ 3, 128, 64, 32, 64, 128, 0, },  //glyph '>' code=29
{ 4, 224, 16, 96, 0, 64, 0, },  //glyph '?' code=30
{ 4, 96, 144, 176, 128, 112, 0, },  //glyph '@' code=31
{ 4, 96, 144, 240, 144, 144, 0, },  //glyph 'A' code=32
{ 4, 224, 144, 224, 144, 224, 0, }, //glyph 'B' code=33
{ 4, 112, 128, 128, 128, 112, 0, }, //glyph 'C' code=34
{ 4, 224, 144, 144, 144, 224, 0, }, //glyph 'D' code=35
{ 4, 240, 128, 224, 128, 240, 0, }, //glyph 'E' code=36
{ 4, 240, 128, 224, 128, 128, 0, }, //glyph 'F' code=37
{ 4, 112, 128, 176, 144, 112, 0, }, //glyph 'G' code=38
{ 4, 144, 144, 240, 144, 144, 0, }, //glyph 'H' code=39
{ 3, 224, 64, 64, 64, 224, 0, },  //glyph 'I' code=40
{ 4, 240, 16, 16, 144, 96, 0, },  //glyph 'J' code=41
{ 4, 144, 160, 192, 160, 144, 0, }, //glyph 'K' code=42
{ 4, 128, 128, 128, 128, 240, 0, }, //glyph 'L' code=43
{ 5, 136, 216, 168, 136, 136, 0, }, //glyph 'M' code=44
{ 4, 144, 208, 176, 144, 144, 0, }, //glyph 'N' code=45
{ 4, 96, 144, 144, 144, 96, 0, }, //glyph 'O' code=46
{ 4, 224, 144, 224, 128, 128, 0, }, //glyph 'P' code=47
{ 4, 96, 144, 144, 144, 96, 16, },  //glyph 'Q' code=48
{ 4, 224, 144, 224, 160, 144, 0, }, //glyph 'R' code=49
{ 4, 112, 128, 96, 16, 224, 0, }, //glyph 'S' code=50
{ 3, 224, 64, 64, 64, 64, 0, }, //glyph 'T' code=51
{ 4, 144, 144, 144, 144, 96, 0, },  //glyph 'U' code=52
{ 3, 160, 160, 160, 160, 64, 0, },  //glyph 'V' code=53
{ 5, 136, 168, 168, 168, 80, 0, },  //glyph 'W' code=54
{ 4, 144, 144, 96, 144, 144, 0, },  //glyph 'X' code=55
{ 3, 160, 160, 64, 64, 64, 0, },  //glyph 'Y' code=56
{ 4, 240, 16, 96, 128, 240, 0, }, //glyph 'Z' code=57
{ 2, 192, 128, 128, 128, 192, 0, }, //glyph '[' code=58
{ 5, 128, 64, 32, 16, 8, 0, },  //glyph '\' code=59
{ 2, 192, 64, 64, 64, 192, 0, },  //glyph ']' code=60
{ 5, 32, 80, 136, 0, 0, 0, }, //glyph '^' code=61
{ 4, 0, 0, 0, 0, 240, 0, }, //glyph '_' code=62
{ 2, 128, 64, 0, 0, 0, 0, },  //glyph '`' code=63
{ 3, 0, 224, 32, 224, 224, 0, },  //glyph 'a' code=64
{ 3, 128, 224, 160, 160, 224, 0, }, //glyph 'b' code=65
{ 3, 0, 224, 128, 128, 224, 0, }, //glyph 'c' code=66
{ 3, 32, 224, 160, 160, 224, 0, },  //glyph 'd' code=67
{ 3, 0, 224, 224, 128, 224, 0, }, //glyph 'e' code=68
{ 2, 64, 128, 192, 128, 128, 0, },  //glyph 'f' code=69
{ 3, 0, 224, 160, 224, 32, 224, },  //glyph 'g' code=70
{ 3, 128, 224, 160, 160, 160, 0, }, //glyph 'h' code=71
{ 1, 128, 0, 128, 128, 128, 0, }, //glyph 'i' code=72
{ 2, 0, 192, 64, 64, 64, 128, },  //glyph 'j' code=73
{ 3, 128, 160, 192, 160, 160, 0, }, //glyph 'k' code=74
{ 1, 128, 128, 128, 128, 128, 0, }, //glyph 'l' code=75
{ 5, 0, 248, 168, 168, 168, 0, }, //glyph 'm' code=76
{ 3, 0, 224, 160, 160, 160, 0, }, //glyph 'n' code=77
{ 3, 0, 224, 160, 160, 224, 0, }, //glyph 'o' code=78
{ 3, 0, 224, 160, 160, 224, 128, }, //glyph 'p' code=79
{ 3, 0, 224, 160, 160, 224, 32, },  //glyph 'q' code=80
{ 3, 0, 224, 128, 128, 128, 0, }, //glyph 'r' code=81
{ 2, 0, 192, 128, 64, 192, 0, },  //glyph 's' code=82
{ 3, 64, 224, 64, 64, 64, 0, }, //glyph 't' code=83
{ 3, 0, 160, 160, 160, 224, 0, }, //glyph 'u' code=84
{ 3, 0, 160, 160, 160, 64, 0, },  //glyph 'v' code=85
{ 5, 0, 168, 168, 168, 80, 0, },  //glyph 'w' code=86
{ 3, 0, 160, 64, 160, 160, 0, },  //glyph 'x' code=87
{ 3, 0, 160, 160, 224, 32, 224, },  //glyph 'y' code=88
{ 2, 0, 192, 64, 128, 192, 0, },  //glyph 'z' code=89
{ 3, 96, 64, 192, 64, 96, 0, }, //glyph '{' code=90
{ 1, 128, 128, 128, 128, 128, 0, }, //glyph '|' code=91
{ 3, 192, 64, 96, 64, 192, 0, },  //glyph '}' code=92
//{ 3, 96, 192, 0, 0, 0, 0, },  //glyph '~' code=93
{ 5, 32, 160, 240, 120, 32, 32, }, //= 'planeR' code=93
{ 4, 48, 64, 224, 64, 240, 0, },  //glyph '£' code=94
};

static const char str0[] PROGMEM="0"; 
static const char str1[] PROGMEM="1"; 
static const char str2[] PROGMEM="2"; 
static const char str3[] PROGMEM="3"; 
static const char str4[] PROGMEM="4"; 
static const char str5[] PROGMEM="5"; 
static const char str6[] PROGMEM="6"; 
static const char str7[] PROGMEM="7"; 
static const char str8[] PROGMEM="8"; 
static const char str9[] PROGMEM="9"; 
static const char str10[] PROGMEM="#"; 
static const char str15[] PROGMEM="Red wins!"; 
static const char str16[] PROGMEM="Green wins!"; 
static const char str18[] PROGMEM="Game Over!!!"; 
static const char str21[] PROGMEM="########";
static const char str30[] PROGMEM="Choose Arduino Game"; 
static const char str31[] PROGMEM="Pong"; 
static const char str32[] PROGMEM="Breakout"; 
static const char str33[] PROGMEM="Bomber"; 
static const char str34[] PROGMEM="Etch-a-Sketch"; 
static const char str35[] PROGMEM="Tetris"; 
static const char str40[] PROGMEM="X"; 
static const char str51[] PROGMEM="~"; //planeR
static const char str52[] PROGMEM="%"; //planeL
static const char str53[] PROGMEM="$"; //bomb
static const char str54[] PROGMEM="'"; //rectangle 5 x 6
static const char str59[] PROGMEM="'''''''"; //clear 'Hit' banner 
static const char str510[] PROGMEM="Hit!!!"; //'Hit' banner
static const char str511[] PROGMEM="Arduino VGA Bomber"; 
static const char str512[] PROGMEM="by Roberto Melzi"; 
static const char str515[] PROGMEM="Game Over!!!"; 

void setup() {
  //Serial.begin(9600); 
  vga.begin();
  randomSeed(1);  
}

// ************* Variable definition Pong ***************************************
unsigned char x,y;
boolean buttonStatus = 0;
boolean buttonOneStatus = 0;
boolean buttonTwoStatus = 0;
int wheelOnePosition; 
int wheelTwoPosition;
byte state = 1;
int rightPaddleY;
int leftPaddleY;
int rightPaddleY0 = 30;
int leftPaddleY0 = 30;
byte ballX = 4;
byte ballY = 20;
byte ballX0 = 21;
byte ballY0 = 21; 
float ballPX = 20;
float ballPY = 20; 
float ballVx;
float ballVy;
byte scoreR = 0;
byte scoreL = 0; 
int PaddleHit = 0; 
byte ticPosition = 12; 
//int xDrawing; --> ballX
//int yDrawing; --> ballY

// ************* Variable definition Breakout ***************************************
int padPosition; 
int padPositionOld; 
//byte PadLenght = 6; 
byte ballXold;
byte ballYold; 
float ballFX = 70.;
float ballFY = 30.;
float speedX; 
float speedY; 
float speedT; 
float angle; 
float angleDeg = 45.; 
byte gameStep = 0; 
boolean cancelSafe = 0;
byte hitScore = 0; 
byte lives = 9; 
int distanceX;
int distanceY; 
int iDel;
int jDel; 
//byte rowBricks = 7; 
int ballXhit; 
int ballYhit; 
static const float pi PROGMEM = 3.1415296;
int nBricks = 0;
int color = 1; 
static const float speedIncrement PROGMEM = 1.25992105; 
int beginning = 0;

// ************* Variable definition Bomber ***************************************
int shot = 12; // ------------ number of frame before next shot is possible ---------------------
int bombX; 
// float bombY; --> float ballFY; 
// float bombV0; --> float angle;
// float bombV0y; --> float angleDeg;
int bombX0;  
// float ballFY0;  --> float ballVx;  
// float ballFY_0; --> float ballVy; 
// float aereoX; --> float speedX; 
// float aereoY; --> float speedY;
// float Vaereo; --> float speedT;
// int ricarica = 0; --> int beginning = 0; 
//int t = 0; --> int iDel; 
int score = 40; 
int frame = 0;
int bombX_0; 
byte planeX;
byte planeY;
byte planeX0;
byte planeY0; 
//int BomberX --> int padPosition; 
//int BomberX0 --> int padPositionOld;


void processInputs() {
  buttonOneStatus = digitalRead(BUTTON_ONE_PIN); 
  buttonTwoStatus = digitalRead(BUTTON_TWO_PIN);
  wheelOnePosition = analogRead(WHEEL_ONE_PIN);
  wheelTwoPosition = analogRead(WHEEL_TWO_PIN);
  buttonStatus = buttonOneStatus || buttonTwoStatus;  // use this in case you connect two buttons ------------------------------
}

void parameterPongIni() { // Pong
  if (rightPaddleY < 30) {
     rightPaddleY0 = rightPaddleY + 1;
  }
  else {
     rightPaddleY0 = rightPaddleY - 1;
  }
  if (leftPaddleY < 30) {
     leftPaddleY0 = leftPaddleY + 1;
  }
  else {
     leftPaddleY0 = leftPaddleY - 1;
  }
  ballVx = random(50., 80.)/500. + (scoreL + scoreR)/35;  
  ballVy = random(40.)/1000. - 0.02;
}

void parameterIniBomber() { // Bomber 
  speedX = 10 + random(VGAX_WIDTH - 20);
  speedY = 10 + random(VGAX_HEIGHT/4);
  bombX0 = speedX;
  ballVx = speedY + 4;
  speedT = 0.1 + random(20)/100.; 
  angle = speedT - random(-10,10)/100.; 
  angleDeg = random(10)/200.; 
  score = 40; 
  lives = 0;
  buttonOneStatus = 0; 
}

void gameIniBreakout(){ // Breakout
  lives = 9; 
  speedT = .06; 
  gameStep = 0; 
  beginning = 0; 
  angleDeg = 180/4; 
  parameterUpdate(); 
  drawLives(); 
  drawBorderBreakout();
  cancelPad(); 
  drawPadBreakout(); 
  drawBricksGrid(gameStep); 
}

void waitForStart(){ // Pong
   buttonStatus = 0; 
   if(scoreR == 8 || scoreR == 0){
      processInputs(); 
      ballY = ((wheelTwoPosition / 8) * (VGAX_HEIGHT-PADDLE_HEIGHT-1))/ 128 + 4;
      drawGameScreen(); 
   }
   if(scoreL == 8){
      processInputs(); 
      ballY = ((wheelOnePosition / 8) * (VGAX_HEIGHT-PADDLE_HEIGHT-1))/ 128 + 4;
      drawGameScreen(); 
    }
    if (buttonStatus == 1){ 
       ballPX = ballX; 
       ballPY = ballY;
       parameterPongIni(); 
       scoreL = 0; 
       scoreR = 0; 
       drawScore(); 
       buttonStatus = 0;
       state = 3; 
    }
}
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
void loop() {
  processInputs(); 
  //if(state == 8) { vga.clear(0); state = 1;}
  if(state == 1 || state == 0) { drawStartMenu(); } 
  if(state == 2) { waitForStart(); }  // Pong
  if(state == 3) { pong(); }
  if(state == 4) { breakout(); }
  if(state == 5) { tetris(); }
  if(state == 6) { bomber(); }
  if(state == 7) { drawingToy(); }
} 
// ------------------------------------------- end of main loop ------------------------------------------------
// -------------------------------------------------------------------------------------------------------------

void drawStartMenu(){
   if (state == 0) {
      state = 1; 
      ballX = 4;
      ballY = 20;
      ballX0 = 21;
      ballY0 = 21; 
      vga.clear(0);
   }
   vgaPrint(str30, 20, 2, 3); 
   vgaPrint(str31, 38, 12, 2); 
   vgaPrint(str32, 38, 20, 2); 
   vgaPrint(str33, 38, 28, 2); 
   vgaPrint(str34, 38, 36, 2); 
   //vgaPrint(str10, 70, 52, 3); 
   //vgaPrint(str35, 38, 44, 2); 
   vgaPrint(str40, 26, ticPosition, 1); 
   vga.delay(50);
   processInputs(); 
   if (buttonTwoStatus == 1){
      buttonOneStatus = 0;
      vgaPrint(str40, 26, ticPosition, 0); 
      ticPosition += 8; 
      if (ticPosition > 36) {ticPosition = 12;}
      vgaPrint(str40, 26, ticPosition, 1);
      vga.delay(200);
   }
   if (buttonOneStatus == 1){ 
      buttonOneStatus = 0;
      buttonTwoStatus = 0;
      buttonStatus = 0; 
      vga.clear(0);
      if (ticPosition == 12) { // Pong
         state = 2;
         ballY = ((wheelTwoPosition / 8) * (VGAX_HEIGHT-PADDLE_HEIGHT-1))/ 128 + 4;
         drawPongStartScreen(); 
      } 
      if (ticPosition == 20) { // Breakout 
         state = 4;
         buttonTwoStatus = 0; 
         buttonOneStatus = 0; 
         buttonStatus = 0; 
         gameIniBreakout(); 
         vga.delay(200); 
      } 
      if (ticPosition == 28) { // Bomber
         parameterIniBomber(); 
         state = 6;
      } 
      if (ticPosition == 36) {state = 7;} // drawingToy
      //if (ticPosition == 44) {state = 5;} // Tetris
   }
}

// ----------------------------------------------- pong -----------------------------------
void pong(){ 
    
     ballPX += ballVx;
     ballPY += ballVy;
     ballX = int(ballPX);
     ballY = int(ballPY);
    
     if(ballPY <= 1 || ballPY >= VGAX_HEIGHT - 2 ) {
        ballVy = -ballVy;
        ballPY += ballVy;
        ballY = int(ballPY);
        vgaTone(880,30); 
     }; 
     
     // ---------------------------------------- left paddle hit -------------------------------------------------
     if(ballVx < 0 && ballX == LEFT_PADDLE_X+PADDLE_WIDTH -1 && ballY >= leftPaddleY - 1 && ballY <= leftPaddleY + PADDLE_HEIGHT) { 
        ballVx = -ballVx;
        ballVy += 0.2 * ((ballY - leftPaddleY + 1) - (PADDLE_HEIGHT / 2)) / (PADDLE_HEIGHT / 2);
        vgaTone(660, 30);
        drawScore();
        PaddleHit = 2; 
        drawPaddles(); 
      }
     //----------------------------------------- right paddle hit --------------------------------------------------
     if(ballVx > 0 && ballX == RIGHT_PADDLE_X - 1 && ballY >= rightPaddleY - 1 && ballY <= rightPaddleY + PADDLE_HEIGHT) { 
        ballVx = -ballVx;
        ballVy += 0.2 * ((ballY - rightPaddleY + 1) - (PADDLE_HEIGHT / 2)) / (PADDLE_HEIGHT / 2);
        vgaTone(660, 30);
        drawScore();
        PaddleHit = 2; 
        drawPaddles(); 
     }
     
     //limit vertical speed
     if(ballVy > MAX_Y_VELOCITY) ballVy = MAX_Y_VELOCITY;
     if(ballVy < -MAX_Y_VELOCITY) ballVy = -MAX_Y_VELOCITY;
     
     if(ballX <= 0) { // ------------------------- ball out from left ------------------------------------------
        vgaTone(220, 200);
        scoreR++; 
        drawScore();  
        ballX = 4;   
        PaddleHit = 1;  
        while(buttonTwoStatus == 0){
           processInputs(); 
           ballY = ((wheelTwoPosition / 8) * (VGAX_HEIGHT-PADDLE_HEIGHT-1))/ 128 + 4;
           drawGameScreen(); 
           PaddleHit = 0; 
        }
        ballPX = ballX; 
        ballPY = ballY;
        parameterPongIni(); 
        drawBorder();
     }
     if(ballX >= VGAX_WIDTH - 2) { // ------------ ball out from right ------------------------------------------
        vgaTone(220, 200); 
        scoreL++; 
        drawScore();      
        ballX = VGAX_WIDTH - 6;   
        PaddleHit = 1; 
        while(buttonOneStatus == 0){
           processInputs(); 
           ballY = ((wheelOnePosition / 8) * (VGAX_HEIGHT-PADDLE_HEIGHT-1))/ 128 + 4;
           drawGameScreen(); 
           PaddleHit = 0; 
        }
        ballPX = ballX; 
        ballPY = ballY;
        parameterPongIni(); 
        drawBorder(); 
        ballVx = -ballVx;
     }
     //if (state == 1) {
     //if (state != 2) {
     if (state == 1 || state == 0) {
        vga.clear(0); 
        vga.delay(300);
     }
     else {drawGameScreen();} // ************************************* Pong end check ******************************
     PaddleHit -= 1; 
     PaddleHit = constrain(PaddleHit, 0, 10); 
  }
// ---------------------------------------- void pong() end ---------------------------------------------


// ----------------------------------------------- breakout -----------------------------------
void breakout(){
  if (beginning == 0){ 
     padPositionOld = padPosition; 
     processInputs();
     padPosition = map(wheelOnePosition, 1023, 0, 7, 93); 
     gameIniBreakout(); 
     ballStart(); 
     beginning = 1; 
  }
  padPositionOld = padPosition; 
  processInputs();
  padPosition = map(wheelOnePosition, 1023, 0, 7, 93); 

  if (padPosition != padPositionOld) {cancelPad(); drawPadBreakout();}
  
  ballCoordinatesBreakout(); 
  
  if ( ballX != ballXold | ballY != ballYold) { 
     if (cancelSafe == 0) {
        drawBallBreakout(ballXold, ballYold, 0); 
        cancelSafe = 1; 
     }
     if (vga.getpixel(ballX, ballY) != 0) {hitScore += 1;}
     if (vga.getpixel(ballX + 1, ballY) != 0) {hitScore += 2;}
     if (vga.getpixel(ballX, ballY + 1) != 0) {hitScore += 4;}
     if (vga.getpixel(ballX + 1, ballY + 1) != 0) {hitScore += 8;}
     if (hitScore == 0) // *************************************** ball did not hit anything and can go ahead ************
     {
        drawBallBreakout(ballX, ballY, 2); 
        cancelSafe = 0; 
     }
     else // ******************************* ball has hit something  ***********************
     {
        if (hitScore == 3 | hitScore == 12) 
        {
           speedY = -speedY;
        }
        else
        {
           if (hitScore == 5 | hitScore == 10) 
           {
              speedX = -speedX;
           }
           else 
           {
              speedX = -speedX;
              speedY = -speedY;
           }
        }
        if (ballY > 55) 
        {
            if (vga.getpixel(ballX, ballY + 1) == 1 | vga.getpixel(ballX + 1, ballY + 1) == 1) // ******* ball hits the paddle *************
           {
              angleDeg = angleDeg - 2*speedX/abs(speedX)*(padPosition - ballX); 
              if (angleDeg < 20) {angleDeg = 20;}
              if (angleDeg > 70) {angleDeg = 70;}
              parameterUpdate(); 
           } 
           else // *************** ball hits the bottom *************************
           {
              
              lives = lives - 1; 
              if (lives |= 0){vgaTone(110,100);}
              drawLives(); 
              //if (state != 1 && state != 0) {ballStart();}
              if (state == 4 ) {ballStart();} 
              cancelSafe = 0; 
              speedY = - abs(speedY); 
           }
        }
        else if (ballX > 1 && ballX + 1 < 99 && ballY > 1) // *********** ball hits a brick *******************
        {
           vgaTone(440,30);
           if (hitScore == 1 | hitScore == 3 ) {ballXhit = ballX; ballYhit = ballY;}
           if (hitScore == 2 | hitScore == 10) {ballXhit = ballX + 1; ballYhit = ballY;}
           if (hitScore == 8 | hitScore == 12) {ballXhit = ballX + 1; ballYhit = ballY + 1;}
           if (hitScore == 4 | hitScore == 5) {ballXhit = ballX; ballYhit = ballY + 1;}
           searchHitBrick(ballXhit, ballYhit); 
        }
        hitScore = 0; 
      }
   }
}
// ---------------------------------------- void breakout() end ---------------------------------------------

// ----------------------------------------------- tetris -----------------------------------
void tetris(){
}
// ---------------------------------------- void tetris() end ---------------------------------------------
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

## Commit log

2024-01-09 Biblioteca VGAx y ejemplos de aplicacion
2024-01-09 KiCad v7 sch brd
    [arduvga.csv, arduvga.kicad_pcb, arduvga.kicad_sch]
2024-01-10 Gabinete Joysticks
    [12.scad, 12.stl, buttoncap-standalone.scad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]
2024-01-10 update sch
    [arduvga.kicad_sch]
2024-01-11 update pcb
    [arduvga.kicad_pcb]
2024-01-11 Plantilla para fabricacion
2024-01-13 add arduino uno footprint
2024-01-16 update case files
    [12.scad, 12.stl, paddleconverter-base.stl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]
2024-01-16 case gcode
2024-01-18 add schematic diagram for the original arcade version of Pong
2024-05-16 add gbr, step files
    [arduvga-B_Cu.gbr, arduvga-B_Mask.gbr, arduvga-B_Paste.gbr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]
